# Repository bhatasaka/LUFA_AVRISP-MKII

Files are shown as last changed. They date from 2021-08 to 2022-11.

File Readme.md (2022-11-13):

# **LUFA AVRISP-MKII**

**Custom PCB designed for the LUFA AVRISP-MKII Project https://github.com/abcminiuser/lufa**

This repo contains the PCB and firmware configuration files for a compact USB-C programming board designed for LUFA's AVRISP-MKII firmware based on an ATMega16u2.  Major thanks to the LUFA project for making this possible!

<div align="center">
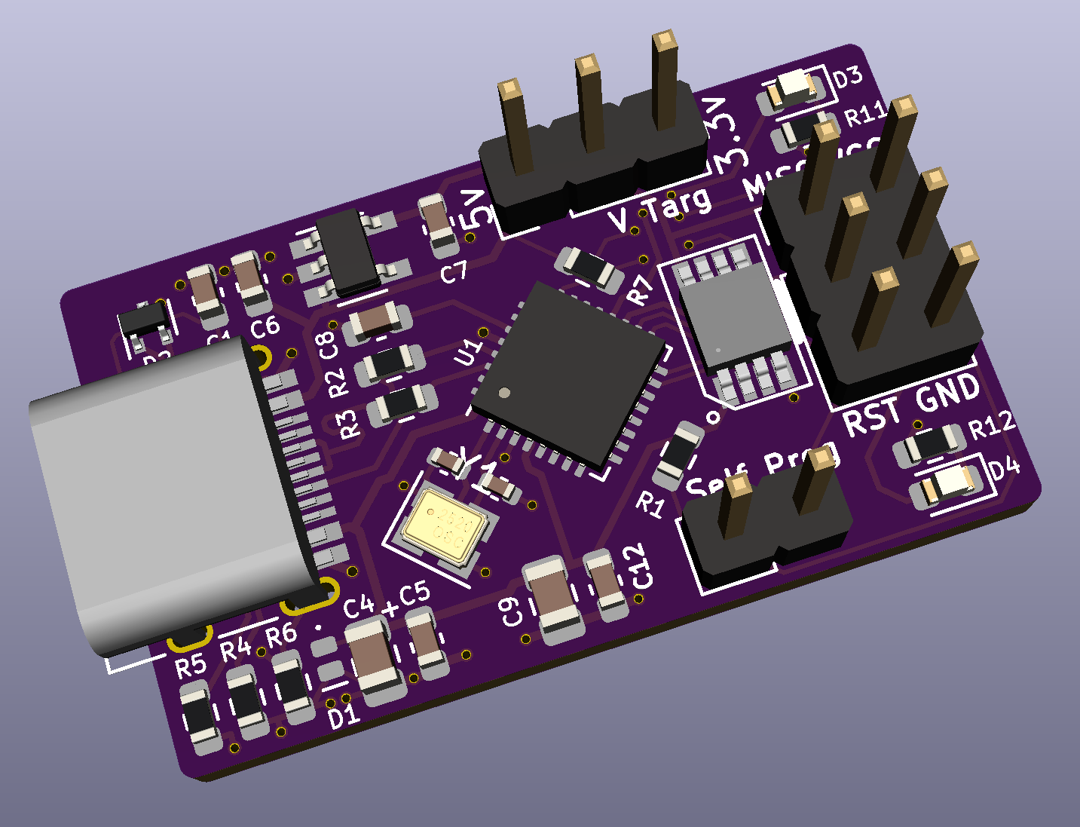
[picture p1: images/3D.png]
PCB 3D View

</div>

## About
---
This PCB is designed only for ISP. However, the PCB could be expanded to break out the PDI and TPI pins as well! It has a level shifter that allows programming of targets other than 5V. Adding a 2-pin jumper to `V Targ` allows the target device to be powered from this board as well. 2 voltages are available - 5v and 3.3v. If you wish to program the 16u2 from the ISP header, the RST pin must be shorted to the 16u2's RST pin, this can be done with a jumper on the `Self Prog` pin header.
## File Structure
---
- `Firmware`
    - Contains configuration files for the LUFA AVRISP-MKII project.
- `KiCad`
    - Contains the KiCad files for the PCB.
- `images`
    - Contains images of the PCB and schematic.

## Firmware Setup and Programming
---
### Setup
1. Clone the repository from https://github.com/abcminiuser/lufa.
1. From this repo's `Firmware` folder, copy and replace the `Config` folder and `makefile` into `Projects/AVRISP-MKII/` in the LUFA repo.
1. From this repo's `Firmware` folder, copy `BHATASAKA` folder into`LUFA/Divers/Board/AVR8` in the LUFA repo.
1. In the LUFA repo, modify `LUFA/Drivers/Board/Board.h` and copy the last `#elif`, then modify it to use `BHATASAKA` as the board name.
1. In the LUFA repo, modify `LUFA/Drivers/Board/LEDs.h` and copy the last `#elif`, then modify it to use `BHATASAKA` as the board name.

### Compiling
Go to `Projects/AVRISP-MKII/` and type `make`. Make sure Make and avr-gcc are installed and in your path.

### Programming
1. The hex file generated in the `Projects/AVRISP-MKII/` folder can be flashed through DFU. Plug the board into your computer. If it is blank it will show up as ATMega 16u2. If it doesn't, reset the chip after it's plugged in.
1. Download Zadig (https://zadig.akeo.ie/) and Atmel Flip (https://www.microchip.com/en-us/development-tool/flip) - make sure you Java SE JRE installed and in your path. Install Flip.
1. Open Zadig and select the 16u2. Install the `libusb-win32` driver for the chip.
1. Open Atmel Flip, select the 16u2, connect to it, load the hex file, and program the chip. It should now show up as an AVRISP-MKII (may need to unplug and replug).

## Usage
---
Install AVRISP-MKII drivers with Zadig (https://zadig.akeo.ie/). Choose `libusb-win32`.
To use with Arduino, select the `AVRISP mkii` programmer. To use with AVRDude, use `-c avrispmkII`.

---
Major thanks to LUFA, KiCad, and Zadig!

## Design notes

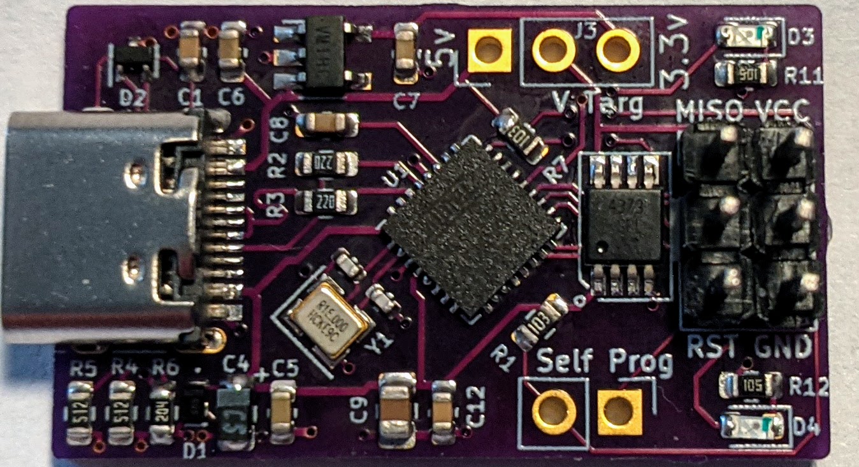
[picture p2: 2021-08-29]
images/front-photo.jpg

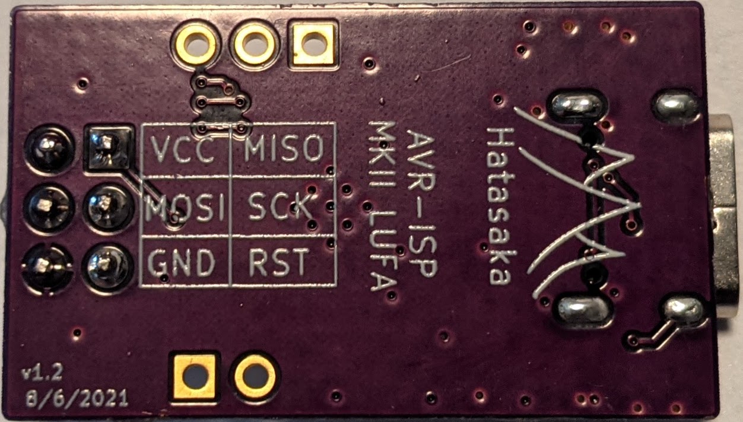
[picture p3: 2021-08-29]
images/back-photo.jpg

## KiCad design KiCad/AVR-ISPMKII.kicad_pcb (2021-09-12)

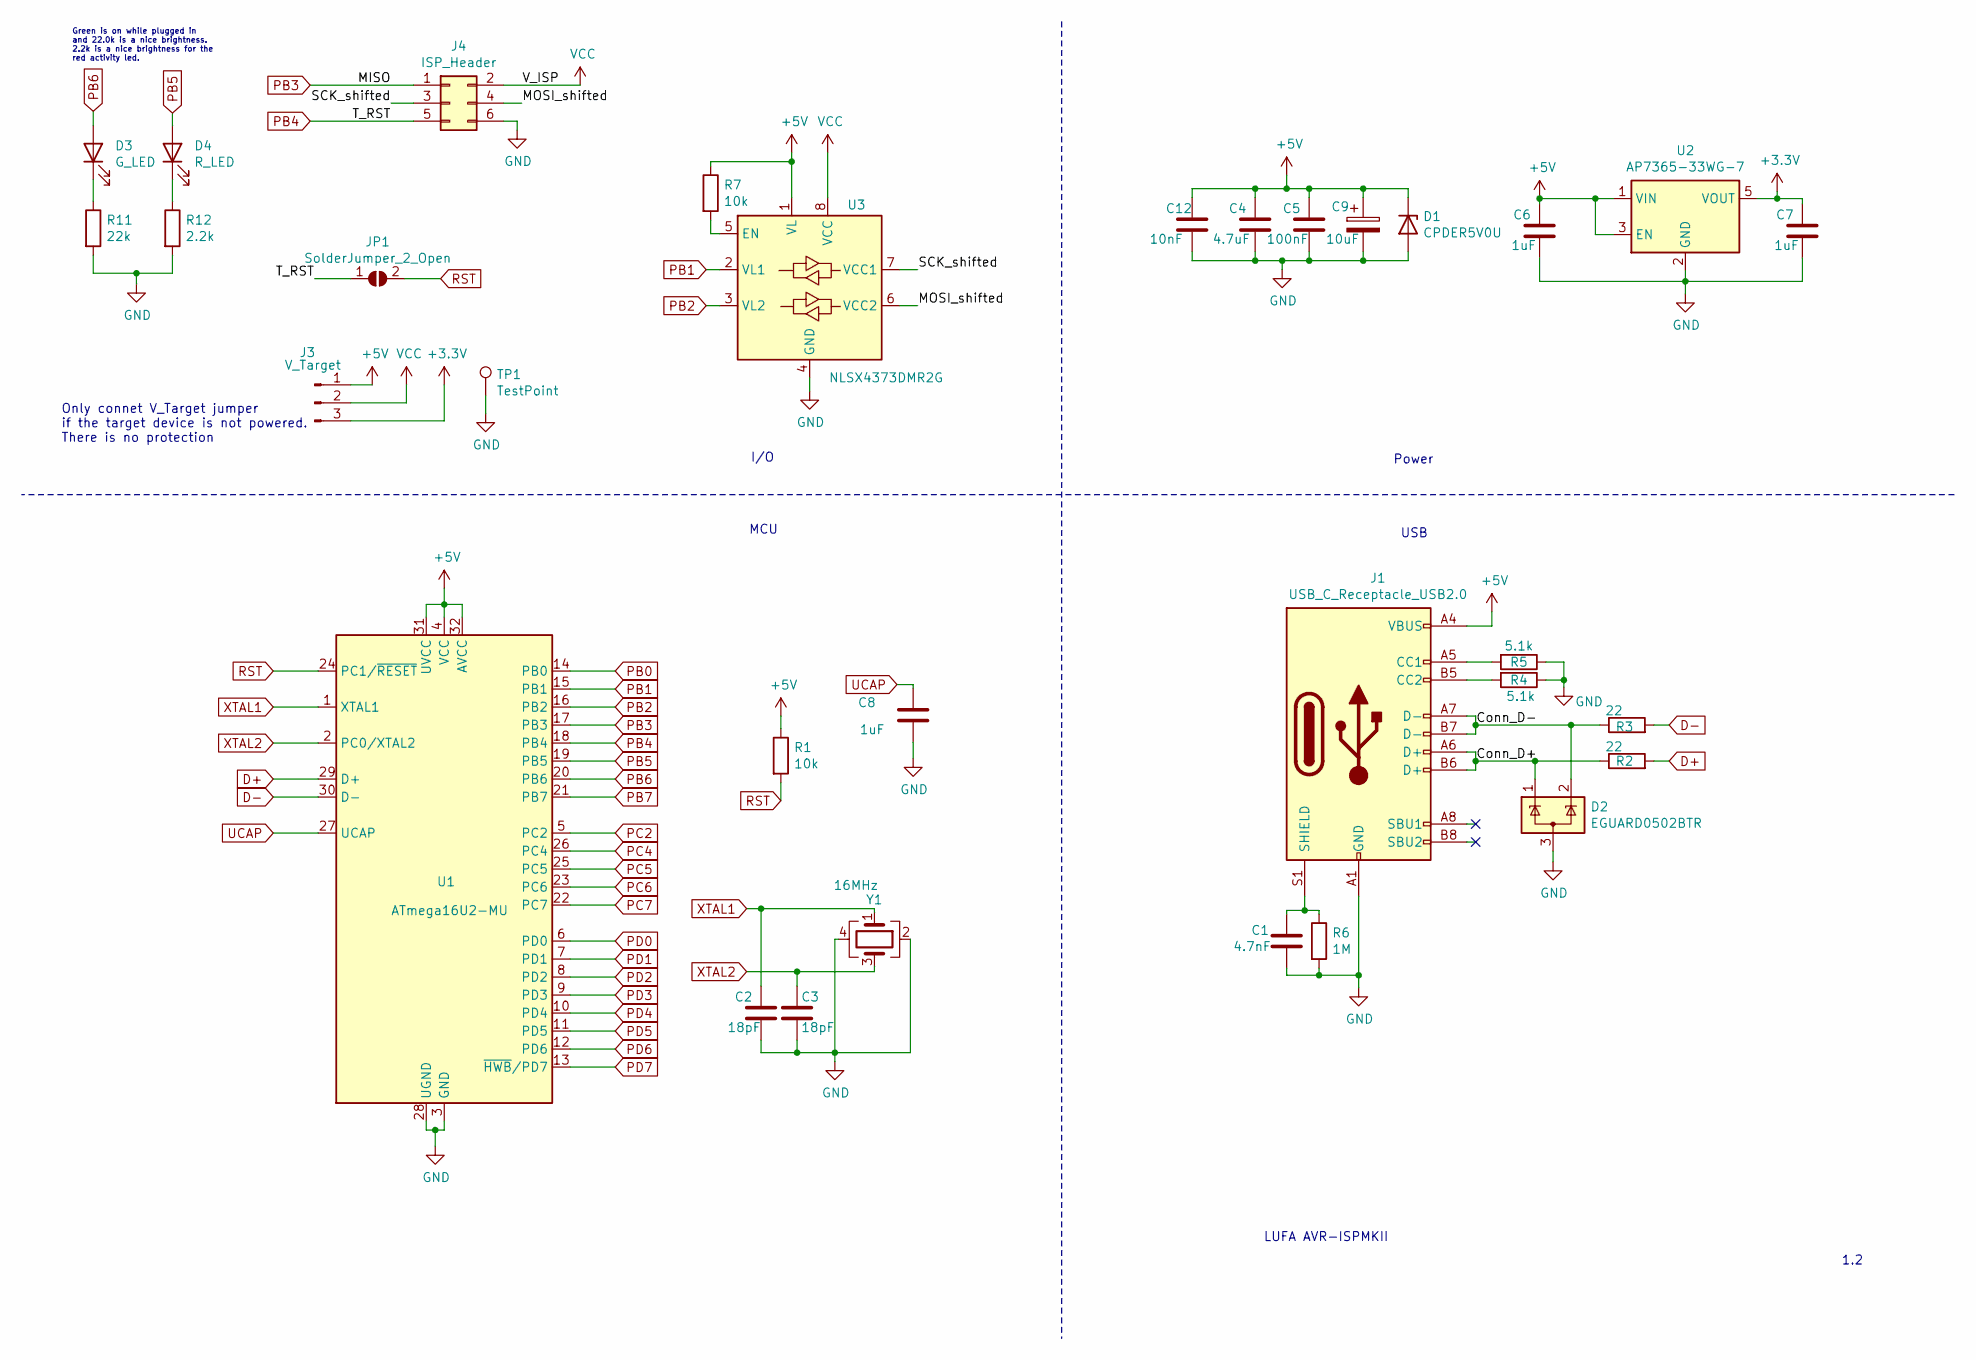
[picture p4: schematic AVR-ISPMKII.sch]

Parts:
C1: 4.7nF; C_0603_1608Metric
C2, C3: 18pF; C_0402_1005Metric
C4: 4.7uF; C_0805_2012Metric
C5: 100nF; C_0603_1608Metric
C6, C7, C8: 1uF; C_0603_1608Metric
C9: 10uF; C_0805_2012Metric
C12: 10nF; C_0603_1608Metric
D1: CPDER5V0U; D_0402_1005Metric
D2: EGUARD0502BTR; SOT-523
D3: G_LED; LED_0603_1608Metric
D4: R_LED; LED_0603_1608Metric
J1: USB_C_Receptacle_USB2.0; USB_C_Receptacle_HRO_TYPE-C-31-M-12
J3: V_Target; PinHeader_1x03_P2.54mm_Vertical
J4: ISP_Header; PinHeader_2x03_P2.54mm_Vertical
JP1: SolderJumper_2_Open; SolderJumper-2_P1.3mm_Open_TrianglePad1.0x1.5mm
R1, R7: 10k; R_0603_1608Metric
R2, R3: 22; R_0603_1608Metric
R4, R5: 5.1k; R_0603_1608Metric
R6: 1M; R_0603_1608Metric
R11: 22k; R_0603_1608Metric
R12: 2.2k; R_0603_1608Metric
TP1: TestPoint; TestPoint_Pad_D2.0mm
U1: ATmega16U2-MU; QFN-32-1EP_5x5mm_P0.5mm_EP3.1x3.1mm
U2: AP7365-33WG-7; TSOT-23-5
U3: NLSX4373DMR2G; TSSOP8
Y1: 16MHz; Crystal_SMD_2520-4Pin_2.5x2.0mm

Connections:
+3V3: C7.1, J3.3, U2.5 (VOUT)
+5V: C4.1, C5.1, C6.1, C9.1, C12.1, D1.1 (K), J1.A4 (VBUS), J1.A9 (VBUS), J1.B4 (VBUS), J1.B9 (VBUS), J3.1, R1.1, R7.1, U1.4 (VCC), U1.31 (UVCC), U1.32 (AVCC), U2.1 (VIN), U2.3 (EN), U3.1 (VL)
/Conn_D+: D2.1 (K), J1.A6 (D+), J1.B6 (D+), R2.1
/Conn_D-: D2.2 (K), J1.A7 (D-), J1.B7 (D-), R3.1
/MOSI_shifted: J4.4, U3.6 (VCC2)
/SCK_shifted: J4.3, U3.7 (VCC1)
D+: R2.2, U1.29 (D+)
D-: R3.2, U1.30 (D-)
GND: C1.2, C2.2, C3.2, C4.2, C5.2, C6.2, C7.2, C8.2, C9.2, C12.2, D1.2 (A), D2.3 (A), J1.A1 (GND), J1.A12 (GND), J1.B1 (GND), J1.B12 (GND), J4.6, R4.1, R5.1, R6.2, R11.2, R12.2, TP1.1, U1.3 (GND), U1.28 (UGND), U1.33 (GND), U2.2 (GND), U3.4 (GND), Y1.2, Y1.4
unnamed: C1.1, J1.S1 (SHIELD), R6.1
unnamed: D3.1 (K), R11.1
unnamed: D4.1 (K), R12.1
unnamed: J1.A5 (CC1), R5.2
unnamed: J1.B5 (CC2), R4.2
unnamed: R7.2, U3.5 (EN)
PB0: U1.14 (PB0)
PB1: U1.15 (PB1), U3.2 (VL1)
PB2: U1.16 (PB2), U3.3 (VL2)
PB3: J4.1, U1.17 (PB3)
PB4: J4.5, JP1.1 (A), U1.18 (PB4)
PB5: D4.2 (A), U1.19 (PB5)
PB6: D3.2 (A), U1.20 (PB6)
PB7: U1.21 (PB7)
PC2: U1.5 (PC2)
PC4: U1.26 (PC4)
PC5: U1.25 (PC5)
PC6: U1.23 (PC6)
PC7: U1.22 (PC7)
PD0: U1.6 (PD0)
PD1: U1.7 (PD1)
PD2: U1.8 (PD2)
PD3: U1.9 (PD3)
PD4: U1.10 (PD4)
PD5: U1.11 (PD5)
PD6: U1.12 (PD6)
PD7: U1.13 (~HWB~/PD7)
RST: JP1.2 (B), R1.2, U1.24 (PC1/~RESET)
UCAP: C8.1, U1.27 (UCAP)
VCC: J3.2, J4.2, U3.8 (VCC)
XTAL1: C2.1, U1.1 (XTAL1), Y1.1
XTAL2: C3.1, U1.2 (PC0/XTAL2), Y1.3

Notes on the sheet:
USB
MCU
I/O
Power
LUFA AVR-ISPMKII
Only connet V_Target jumper if the target device is not powered. There is no protection
1.2
Green is on while plugged in and 22.0k is a nice brightness. 2.2k is a nice brightness for the red activity led.

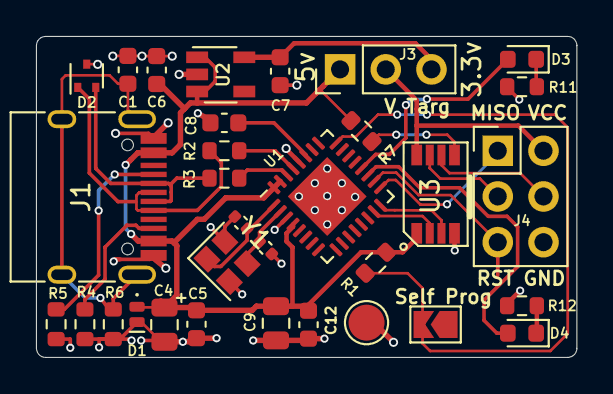
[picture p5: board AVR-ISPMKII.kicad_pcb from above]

Board: 2 copper layers, 30.0 x 17.8 mm, 32 parts (0 on the bottom side), 26 nets.

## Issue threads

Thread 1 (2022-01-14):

Also need to update LEDs.h

llinjupt, 2022-01-14:
Hi Bhatasaka.

Many thanks to you and your work helps me alot. There is a subtle issue that also need to update LEDs.h:

```
#elif (BOARD == BHATASAKA)
			#include "AVR8/BHATASAKA/LEDs.h"
#else
```

BTW, would you like to introduce more  about how to break out  PDI and TPI pins ? THX again.

bhatasaka, 2022-11-13:
Hi, very sorry about no reply on this issue. Thanks for reporting the missing instruction, it has been corrected in 19ef91c1d273f527eec5a1edc399e1bc54e3a88e and the instructions on breaking out PDI and TPI may be added later.

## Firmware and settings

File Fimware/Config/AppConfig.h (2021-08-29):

/*
             LUFA Library
     Copyright (C) Dean Camera, 2021.

  dean [at] fourwalledcubicle [dot] com
           www.lufa-lib.org
*/

/*
  Copyright 2021  Dean Camera (dean [at] fourwalledcubicle [dot] com)

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
  The author disclaims all warranties with regard to this
  software, including all implied warranties of merchantability
  and fitness.  In no event shall the author be liable for any
  special, indirect or consequential damages or any damages
  whatsoever resulting from loss of use, data or profits, whether
  in an action of contract, negligence or other tortious action,
  arising out of or in connection with the use or performance of
  this software.
*/

/** \file
 *  \brief Application Configuration Header File
 *
 *  This is a header file which is be used to configure some of
 *  the application's compile time options, as an alternative to
 *  specifying the compile time constants supplied through a
 *  makefile or build system.
 *
 *  For information on what each token does, refer to the
 *  \ref Sec_Options section of the application documentation.
 */

#ifndef _APP_CONFIG_H_
#define _APP_CONFIG_H_

	#define AUX_LINE_PORT              PORTB
	#define AUX_LINE_PIN               PINB
	#define AUX_LINE_DDR               DDRB
	#if (BOARD == BOARD_U2S)
		#define AUX_LINE_MASK          (1 << 0)
	#else
		#define AUX_LINE_MASK          (1 << 4)
	#endif

	#define ENABLE_ISP_PROTOCOL

	#define VTARGET_ADC_CHANNEL        0
	#define VTARGET_REF_VOLTS          5
	#define VTARGET_SCALE_FACTOR       1
//	#define VTARGET_USE_INTERNAL_REF
	#define NO_VTARGET_DETECT
//	#define XCK_RESCUE_CLOCK_ENABLE
//	#define INVERTED_ISP_MISO

//	#define FIRMWARE_VERSION_MINOR     0x11

#endif

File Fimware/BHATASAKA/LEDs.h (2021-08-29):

/*
             LUFA Library
     Copyright (C) Dean Camera, 2021.

  dean [at] fourwalledcubicle [dot] com
           www.lufa-lib.org
*/

/*
  Copyright 2021  Dean Camera (dean [at] fourwalledcubicle [dot] com)

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
  The author disclaims all warranties with regard to this
  software, including all implied warranties of merchantability
  and fitness.  In no event shall the author be liable for any
  special, indirect or consequential damages or any damages
  whatsoever resulting from loss of use, data or profits, whether
  in an action of contract, negligence or other tortious action,
  arising out of or in connection with the use or performance of
  this software.
*/

/** \file
 *  \brief Board specific LED driver header for the custom PCB made by Bryan Hatasaka.
 *  \copydetails Group_LEDs_BHATASAKA
 *
 *  \note This file should not be included directly. It is automatically included as needed by the LEDs driver
 *        dispatch header located in LUFA/Drivers/Board/LEDs.h.
 */

/** \ingroup Group_LEDs
 *  \defgroup Group_LEDs_BHATASAKA BHATASAKA
 *  \brief Board specific LED driver header for the custom PCB made by Bryan Hatasaka.
 *
 *  Board specific LED driver header for the custom PCB made by Bryan Hatasaka.
 * 	There are only 2 LEDs on the PCB but a third could be added, this file configures it
 *  for PB7 as active high.
 *
 *  <table>
 *    <tr><th>Name</th><th>Color</th><th>Info</th><th>Active Level</th><th>Port Pin</th></tr>
 *    <tr><td>LEDS_LED1</td><td>Red</td><td>RX</td><td>High</td><td>PORTB.5</td></tr>
 *    <tr><td>LEDS_LED2</td><td>Green</td><td>TX</td><td>High</td><td>PORTB.6</td></tr>
 *  </table>
 *
 *  @{
 */

#ifndef __LEDS_BHATASAKA_H__
#define __LEDS_BHATASAKA_H__

	/* Includes: */
		#include "../../../../Common/Common.h"

	/* Enable C linkage for C++ Compilers: */
		#if defined(__cplusplus)
			extern "C" {
		#endif

	/* Preprocessor Checks: */
		#if !defined(__INCLUDE_FROM_LEDS_H)
			#error Do not include this file directly. Include LUFA/Drivers/Board/LEDS.h instead.
		#endif

	/* Private Interface - For use in library only: */
	#if !defined(__DOXYGEN__)
		/* Macros: */
			#define LEDS_PORTB_LEDS       (LEDS_LED1 | LEDS_LED2 | LEDS_LED3)
	#endif

	/* Public Interface - May be used in end-application: */
		/* Macros: */
			/** LED mask for the first LED on the board. */
			#define LEDS_LED1        (1 << 5)

			/** LED mask for the second LED on the board. */
			#define LEDS_LED2        (1 << 6)

			/** LED mask for the third LED on the board. */
			#define LEDS_LED3        (1 << 7)

			/** LED mask for all the LEDs on the board. */
			#define LEDS_ALL_LEDS    LEDS_PORTB_LEDS

			/** LED mask for none of the board LEDs. */
			#define LEDS_NO_LEDS     0

		/* Inline Functions: */
		#if !defined(__DOXYGEN__)
			static inline void LEDs_Init(void)
			{
				DDRB  |=  LEDS_ALL_LEDS;
				PORTB &=  ~LEDS_ALL_LEDS;
			}

			static inline void LEDs_Disable(void)
			{
				DDRB  &= ~LEDS_PORTB_LEDS;
				PORTB &= ~LEDS_PORTB_LEDS;
			}

			static inline void LEDs_TurnOnLEDs(const uint8_t LEDMask)
			{
				PORTB |= (LEDMask & LEDS_PORTB_LEDS);
			}

			static inline void LEDs_TurnOffLEDs(const uint8_t LEDMask)
			{
				PORTB &= ~(LEDMask & LEDS_PORTB_LEDS);
			}

			static inline void LEDs_SetAllLEDs(const uint8_t LEDMask)
			{
				PORTB = ((PORTB & ~LEDS_PORTB_LEDS) | (LEDMask & LEDS_PORTB_LEDS));
			}

			static inline void LEDs_ChangeLEDs(const uint8_t LEDMask,
			                                   const uint8_t ActiveMask)
			{
				PORTB = ((PORTB & ~(LEDS_PORTB_LEDS & LEDMask)) | (ActiveMask & LEDS_PORTB_LEDS));
			}

			static inline void LEDs_ToggleLEDs(const uint8_t LEDMask)
			{
				PINB  = (LEDMask & LEDS_PORTB_LEDS);
			}

			static inline uint8_t LEDs_GetLEDs(void) ATTR_WARN_UNUSED_RESULT;
			static inline uint8_t LEDs_GetLEDs(void)
			{
				return (PORTB & LEDS_PORTB_LEDS);
			}
		#endif

	/* Disable C linkage for C++ Compilers: */
		#if defined(__cplusplus)
			}
		#endif

#endif

/** @} */

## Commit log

2021-08-29 Initial commmit of PCB v1.2
    [AVR-ISPMKII.kicad_pcb, AVR-ISPMKII.sch]
2021-08-29 Updated LED resistors, corrected .gitignore
    [AVR-ISPMKII.sch]
2021-09-12 Updated USB trace
    [AVR-ISPMKII.kicad_pcb, AVR-ISPMKII.sch]
2022-11-13 Corrected instructions to add the need to update LEDs.h in the LUFA repo
